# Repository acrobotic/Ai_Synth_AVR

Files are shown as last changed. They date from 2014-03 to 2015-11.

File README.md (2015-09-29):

## Ai\_Synth\_AVR

PCB design files (EAGLE) and example Arduino firmware for a MIDI Synthesizer
based on the ATMega328 MCU.

## Description

For more details, check out the product page at:

   * https://acrobotic.com/kit-00002

Designed by ACROBOTIC Industries.  Please consider buying products from us to 
help fund future Open-Source projects like this! We’ll always put our best 
effort in every project, and release all our design files and code for you to 
use. 

## License

Released under the Creative Commons Attribution, Share-Alike license. Please 
check LICENSE.txt for more information. All text above must be included in any 
redistribution.

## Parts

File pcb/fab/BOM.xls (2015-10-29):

Ai Synth AVR – BOM
Cisco Zabala (x1sc0@acrobotic.com) last updated: 29.10.2015
Manufacturer | Manuf. Part Number | Vendor | Vendor Part Number | Type | Designator | Qty | Description | Case | SMD, BGA, LCC, OR TH | Notes
 |  | Acrobotic | RES-00034-103 | Resistors | R1, R6 | 2 | RES 10K OHM 1/4W 5% CARBON FILM |  | TH
 |  | Acrobotic | RES-00034-271 |  | R2, R3, R5 | 3 | RES 270 OHM 1/4W 5% CARBON FILM |  | TH
 |  | Acrobotic | RES-00034-221 |  | R4 | 1 | RES 220 OHM 1/4W 5% CARBON FILM |  | TH
 |  | Acrobotic | RES-00034-472 |  | R7 | 1 | RES 4.7K OHM 1/4W 5% CARBON FILM |  | TH
 |  | Acrobotic | RES-00010 | Pots | VR1, VR2, VR3, VR4, VR5 | 5 | POT ROTARY 10K OHM 9MM SNAPIN |  | TH
 |  | Acrobotic | RES-00011 |  | VR6 | 1 | TRIMMER 10K OHM 0.2W PC PIN |  | TH | OPTIONAL
 |  | Acrobotic | CAP-00003 | Capacitors | C1, C2 | 2 | CAP ALUM 4.7UF 50V 20% RADIAL |  | TH
 |  | Acrobotic | CAP-00001 | Cap. | C3, C4 | 2 | CAP CER 22PF 50V 5% RADIAL |  | TH
 |  | Acrobotic | CAP-00004 | Cap. | C5, C6 | 2 | CAP CER 0.047UF 50V 10% RADIAL |  | TH
 |  | Acrobotic | CAP-00002 | Cap. | C7 | 1 | CAP CER 0.1UF 50V 10% RADIAL |  | TH
 |  | Acrobotic | IND-00001 | Inductors | L1, L2 | 2 | INDUCTOR FIXED 4700UH 5% RADIAL |  | TH
 |  | Acrobotic | DIO-00001 | Diodes | D1 | 1 | DIODE SMALL SIG 100V 0.2A DO35 |  | TH
 |  | Acrobotic | DIO-00007 |  | D2 | 1 | DIODE GEN PURPOSE 50V 1A DO41 |  | TH
 |  | Acrobotic | FRQ-00001 | Crystal | Q1 | 1 | CRYSTAL 16MHZ 18PF THRU |  | TH
 |  | Acrobotic | CHP-00001 | ICs | (IC1) | 1 | IC MCU 8BIT 32KB FLASH 28DIP |  | TH
 |  | Acrobotic | CHP-00004 | IC | U1 | 1 | IC REG LDO 5V 1.5A TO220 |  | TH
 |  | Acrobotic | CHP-00005 | IC | (U2) | 1 | IC OPAMP GP R-R 730KHZ DUAL 8DIP |  | TH
 |  | Acrobotic | CHP-00006 | IC | (U3) | 1 | OPTOPCOUPLER DARL 5KVRMS 8DIP |  | TH
 |  | Acrobotic | BTN-00002 | Buttons | S1, S2, S3, S4, S5, S6, S7 | 7 | SWITCH TACTILE SPST-NO 0.05A 12V |  | TH
 |  | Acrobotic | BTN-00003 | Switches | S8 | 1 | SWITCH SLIDE SPDT 30V.2A PC MNT |  | TH | ON/OFF
 |  | Acrobotic | CON-00007 | Connectors | J1 | 1 | 2-Pin Screw Terminal Block (3.5mm) |  | TH | PWR
 |  | Acrobotic | CON-00005 | Connect. | J2 | 1 | 0.1" Pitch, 6-Pin (Male, R/A) |  | TH | FTDI
 |  | Acrobotic | CON-00004 | Connect. | J3, J4 | 2 | 0.1" Pitch, 8-Pin (Female) |  | TH | LCD
 |  | Acrobotic | CON-00015 | Connectors | J5 | 1 | CONN DIN 5 PIN FEMALE PCB |  | TH | MIDIJACK
 |  | Acrobotic | CON-00013 | Connect. | 3.5mm | 1 | CONN JACK STEREO R/A 3PIN 3.5MM |  | TH | AUDIOJACK
 |  | Acrobotic | CON-00017 | Socket | U2, U3 | 2 | CONN IC SOCKET VERT 8POS TIN |  | TH | IC SOCKET
 |  | Acrobotic | CON-00016 | Socket | IC1 | 1 | CONN IC SOCKET VERT 28POS TIN |  | TH | IC SOCKET
 |  | Acrobotic | PWR-00007 | Connect. | (J1) | 1 | SNAPS 9V 6" LEADS l-STYLE |  | TH | PWR
 |  | Acrobotic | CON-00010 |  | ISP | 1 | CONN HEADER 6POS .100" VERT 15AU |  | TH | ICSP
 |  | Acrobotic | CON-00002 | Connect. | (J3, J4) | 2 | 0.1” Pitch, 8-Pin (Male) |  | TH | LCD HEADERS
 |  | Acrobotic | LCD-00001 | LCD | (J3, J4) | 1 | Graphic LCD 84x48 - Nokia 5110 |  | TH | LCD MODULE
 |  | Acrobotic | HWR-00002 | Hardware | - | 4 | 4-40 x 7/16" Female / Female Stand-off (3/16" Hex) |  | - | MOUNTS
 |  | Acrobotic | HWR-00024 |  | - | 4 | 4-40 x 3/16" Machine Screws (Phillips Head) |  | - | MOUNTS

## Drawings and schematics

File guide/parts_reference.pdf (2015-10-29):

## ACROBOTIC AVR Synthesizer - Parts List

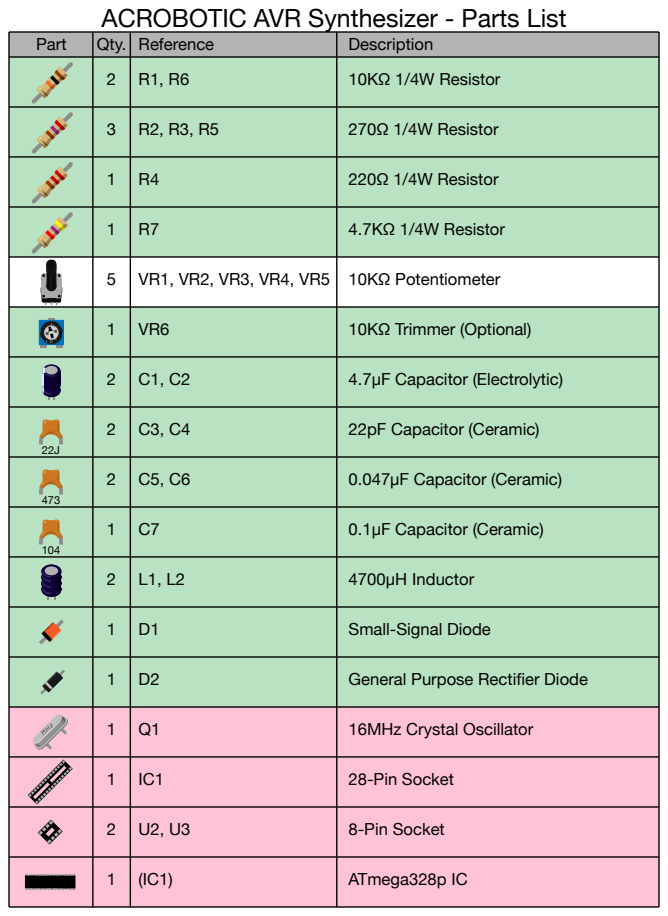
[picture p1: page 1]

Part | Qty. | Reference | Description
2 | R1, R6 | 10KΩ 1/4W Resistor

3 | R2, R3, R5 | 270Ω 1/4W Resistor

1 | R4 | 220Ω 1/4W Resistor

1 | R7 | 4.7KΩ 1/4W Resistor

5 | VR1, VR2, VR3, VR4, VR5 | 10KΩ Potentiometer

1 | VR6 | 10KΩ Trimmer (Optional)

2 | C1, C2 | 4.7μF Capacitor (Electrolytic)

22J | | | 2 | C3, C4 | 22pF Capacitor (Ceramic)

473 | | | 2 | C5, C6 | 0.047μF Capacitor (Ceramic)

104 | | | 1 | C7 | 0.1μF Capacitor (Ceramic)

2 | L1, L2 | 4700μH Inductor

1 | D1 | Small-Signal Diode

1 | D2 | General Purpose Rectifier Diode

1 | Q1 | 16MHz Crystal Oscillator

1 | IC1 | 28-Pin Socket

2 | U2, U3 | 8-Pin Socket

1 | (IC1) | ATmega328p IC

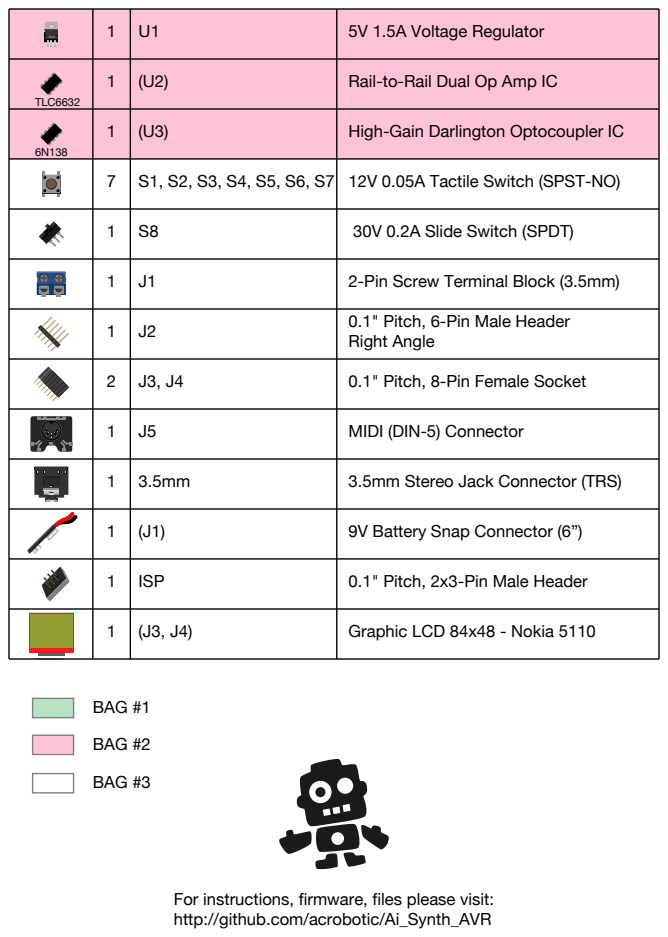
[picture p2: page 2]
BAG #1 BAG #2 BAG #3; 78xxl

1 | U1 | 5V 1.5A Voltage Regulator

TLC6632 | 1 | (U2) | Rail-to-Rail Dual Op Amp IC

6N138 | 1 | (U3) | High-Gain Darlington Optocoupler IC

7 | S1, S2, S3, S4, S5, S6, S7 | 12V 0.05A Tactile Switch (SPST-NO)

1 | S8 | 30V 0.2A Slide Switch (SPDT)

1 | J1 | 2-Pin Screw Terminal Block (3.5mm)
J2 | 0.1" Pitch, 6-Pin Male Header Right Angle 1

2 | J3, J4 | 0.1" Pitch, 8-Pin Female Socket

1 | J5 | MIDI (DIN-5) Connector

1 | 3.5mm | 3.5mm Stereo Jack Connector (TRS)

1 | (J1) | 9V Battery Snap Connector (6”)

1 | ISP | 0.1" Pitch, 2x3-Pin Male Header

1 | (J3, J4) | Graphic LCD 84x48 - Nokia 5110

For instructions, firmware, files please visit:
http://github.com/acrobotic/Ai_Synth_AVR

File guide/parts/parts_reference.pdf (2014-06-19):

## Acrobotic AVR Synthesizer

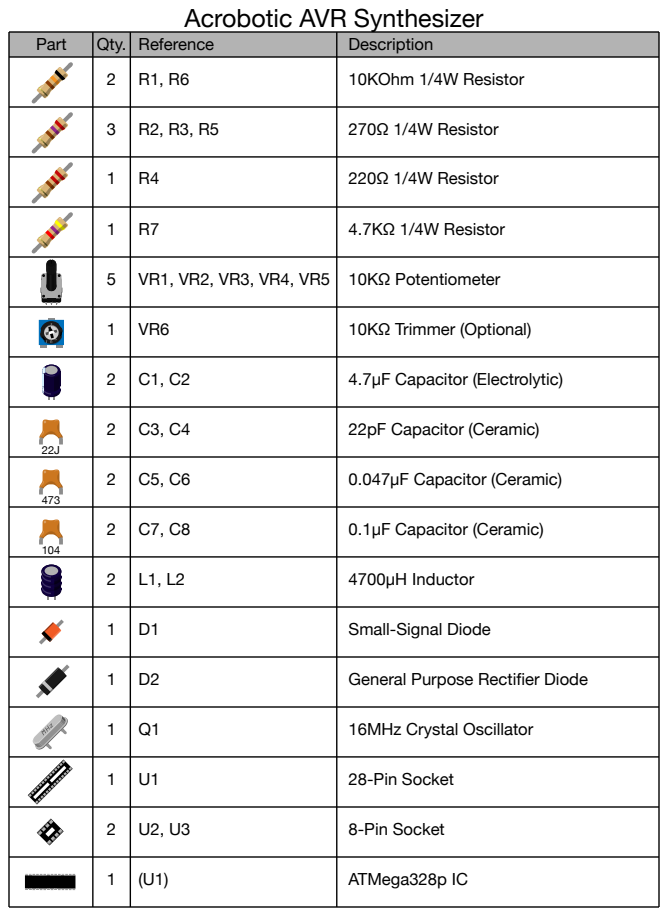
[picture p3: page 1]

Part | Qty. | Reference | Description
2 | R1, R6 | 10KOhm 1/4W Resistor

3 | R2, R3, R5 | 270Ω 1/4W Resistor

1 | R4 | 220Ω 1/4W Resistor

1 | R7 | 4.7KΩ 1/4W Resistor

5 | VR1, VR2, VR3, VR4, VR5 | 10KΩ Potentiometer

1 | VR6 | 10KΩ Trimmer (Optional)

2 | C1, C2 | 4.7μF Capacitor (Electrolytic)

22J | | | 2 | C3, C4 | 22pF Capacitor (Ceramic)

473 | | | 2 | C5, C6 | 0.047μF Capacitor (Ceramic)

104 | | | 2 | C7, C8 | 0.1μF Capacitor (Ceramic)

2 | L1, L2 | 4700μH Inductor

1 | D1 | Small-Signal Diode

1 | D2 | General Purpose Rectifier Diode

1 | Q1 | 16MHz Crystal Oscillator

1 | U1 | 28-Pin Socket

2 | U2, U3 | 8-Pin Socket

1 | (U1) | ATMega328p IC

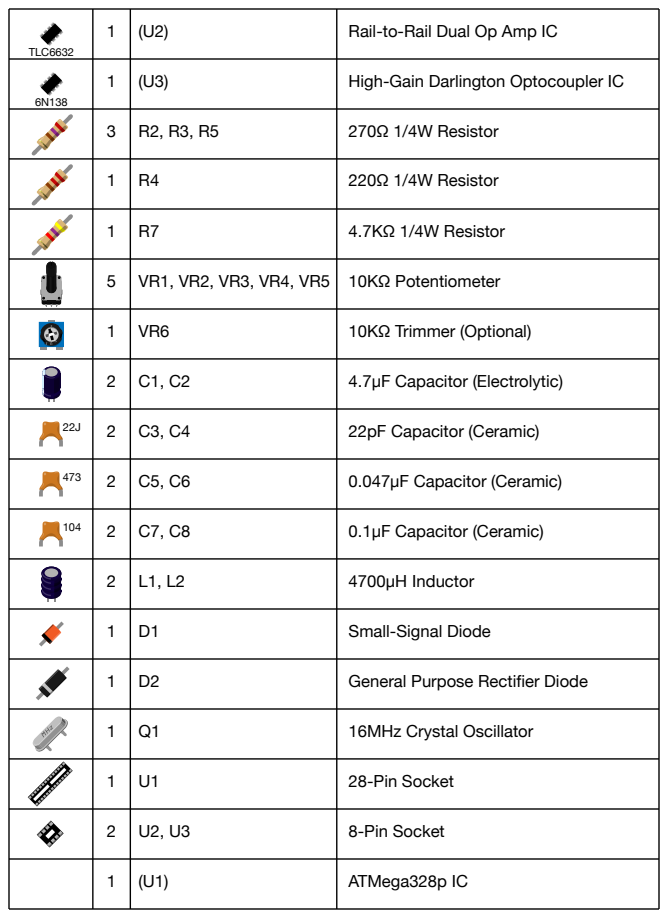
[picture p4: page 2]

TLC6632 | 1 | (U2) | Rail-to-Rail Dual Op Amp IC

6N138 | 1 | (U3) | High-Gain Darlington Optocoupler IC

3 | R2, R3, R5 | 270Ω 1/4W Resistor

1 | R4 | 220Ω 1/4W Resistor

1 | R7 | 4.7KΩ 1/4W Resistor

5 | VR1, VR2, VR3, VR4, VR5 | 10KΩ Potentiometer

1 | VR6 | 10KΩ Trimmer (Optional)

2 | C1, C2 | 4.7μF Capacitor (Electrolytic)

2 | C3, C4 | 22pF Capacitor (Ceramic) ²²J

473 | | | 2 | C5, C6 | 0.047μF Capacitor (Ceramic)

104 | | | 2 | C7, C8 | 0.1μF Capacitor (Ceramic)

2 | L1, L2 | 4700μH Inductor

1 | D1 | Small-Signal Diode

1 | D2 | General Purpose Rectifier Diode

1 | Q1 | 16MHz Crystal Oscillator

1 | U1 | 28-Pin Socket

2 | U2, U3 | 8-Pin Socket

1 | (U1) | ATMega328p IC

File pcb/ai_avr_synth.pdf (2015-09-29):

1

2

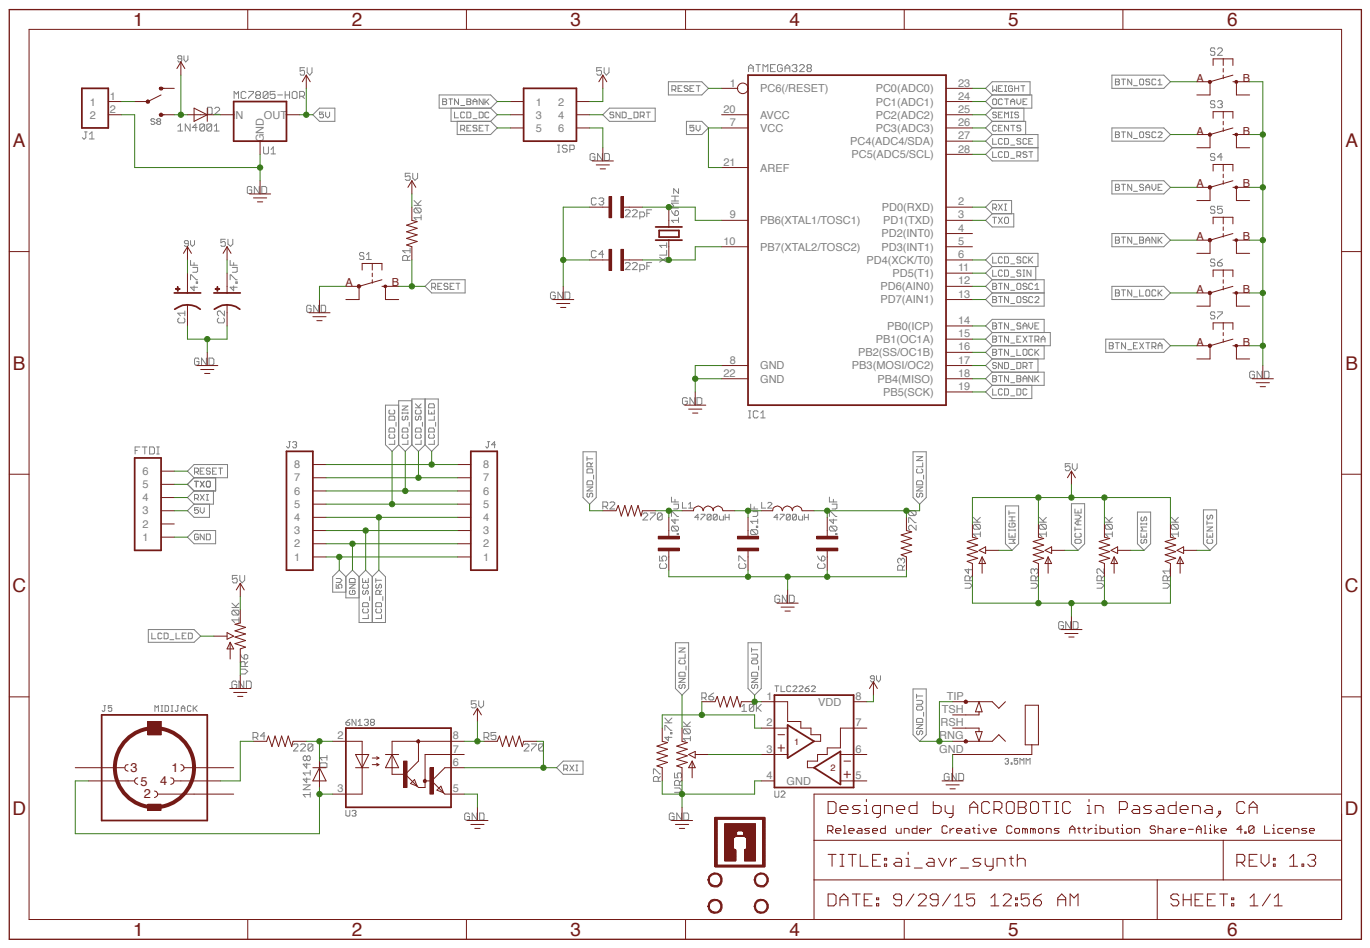
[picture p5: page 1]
GNDOUT; PB5(SCK); PB7(XTAL2/TOSC2) 10; PB6(XTAL1/TOSC1); GND; 8 GND 22; VCC; AREF 21; AVCC 20; PB4(MISO); 18 PB3(MOSI/OC2); 15 PB0(ICP); PD7(AIN1); 13 PD6(AIN0); 11 PD4(XCK/T0); 6 PD3(INT1); 5 PD2(INT0); 4 PD1(TXD); 3 PD0(RXD); PC5(ADC5/SCL); 28 PC4(ADC4/SDA); 27 PC3(ADC3); 26 PC2(ADC2); 25 PC1(ADC1); 24 PC0(ADC0); 23 PC6(/RESET); VDD; TIP TSH RSH RNG GND; ABCD

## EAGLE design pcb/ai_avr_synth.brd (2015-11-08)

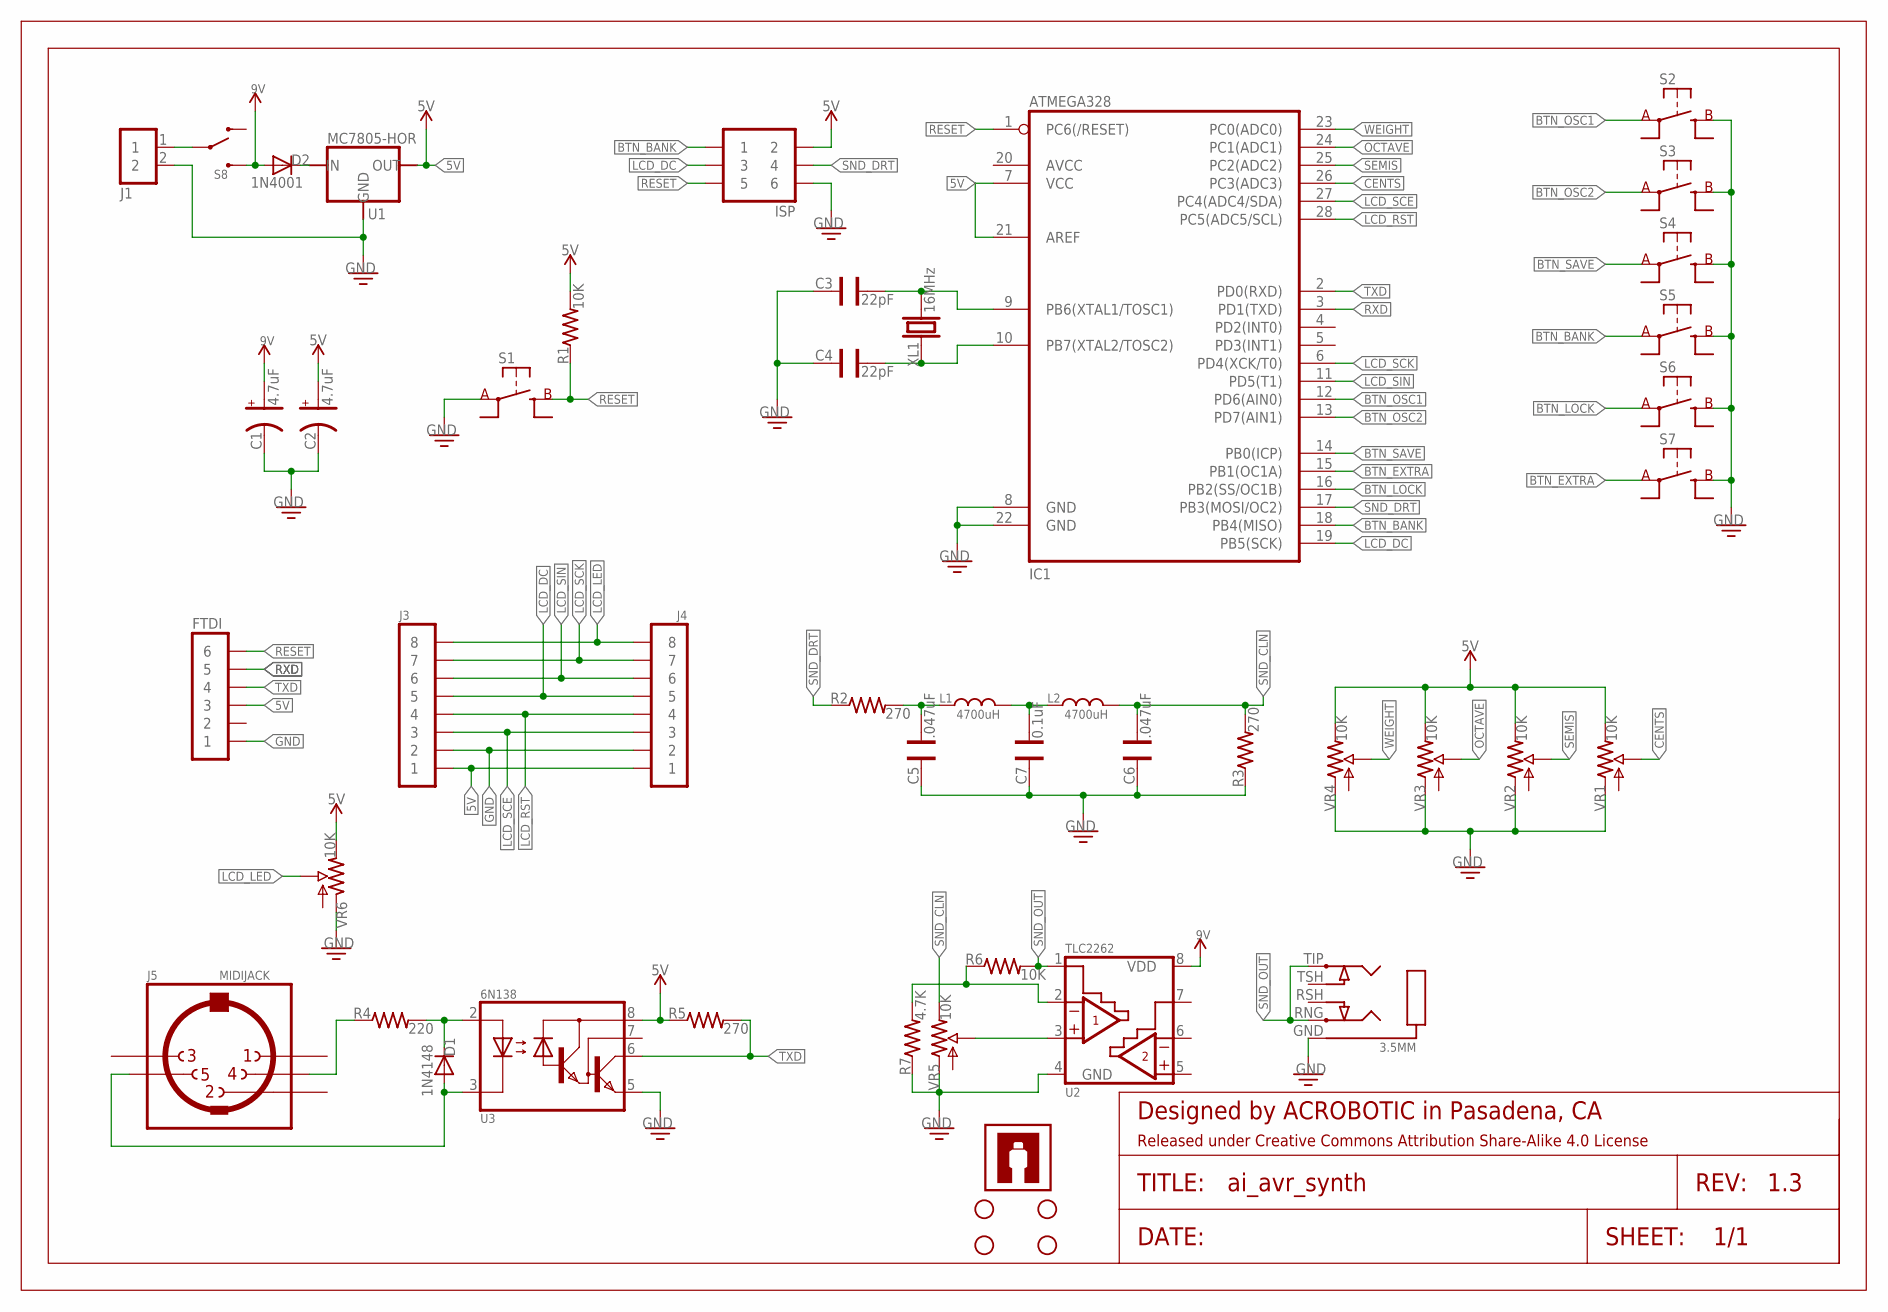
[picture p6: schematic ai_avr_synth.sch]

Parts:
3.5MM: STEREOJACKSJ1-351XNG; SJ1-351XNG
C1, C2: 4.7uF; CAP-POL-025X50
C3, C4: 22pF; CAP-025X050
C5, C6: .047uF; CAP-025X050
C7: 0.1uF; CAP-025X050
D1: 1N4148; TH-1N914
D2: 1N4001; TH-1N914
FRAME1: FRAME-LETTER; CREATIVE-COMMONS
FTDI: 1X06
IC1: ATMEGA328P-PDIP; DIL28
ISP: 2X03
J1: 1X02ST; 1X02-ST
J3, J4: 1X08
J5: MIDIJACK; CP-2350
L1, L2: 4700uH; RLB0912
R1, R6: 10K; RES-AXIAL-0.4
R2, R3, R5: 270; RES-AXIAL-0.4
R4: 220; RES-AXIAL-0.4
R7: 4.7K; RES-AXIAL-0.4
S1, S2, S3, S4, S5, S6, S7: SW-SPSTTH06X06; SW-SPST-TH06X06
S8: SW-SPDTTH; SW-SPDT-TH
STANDOFF5, STANDOFF6, STANDOFF7, STANDOFF8: STAND-OFF4; STAND-OFF-4
U1: MC7805-HOR; TO220
U2: TLC2262; DIL08
U3: 6N138; DIL08
U$5: AI-LOGOXS; AI-LOGO-XS
VR1, VR2, VR3, VR4, VR5: 10K; POT-09X09
VR6: 10K; POT-05X05
XL1: 16MHz; HC49S

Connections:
5V: C2.A, FTDI.3, IC1.7 (VCC), IC1.21 (AREF), ISP.2, J3.1, J4.1, R1.P$2 (2), R5.P$1 (1), U1.OUT, U3.8 (VCC), VR1.P$1 (E), VR2.P$1 (E), VR3.P$1 (E), VR4.P$1 (E), VR6.1 (E)
9V: C1.A, D2.A, S8.3 (L2), U2.8 (VDD)
BTN_BANK: IC1.18 (PB4(MISO)), ISP.1, S5.A@1 (A)
BTN_EXTRA: IC1.15 (PB1(OC1A)), S7.A@1 (A)
BTN_LOCK: IC1.16 (PB2(SS/OC1B)), S6.A@1 (A)
BTN_OSC1: IC1.12 (PD6(AIN0)), S2.A@1 (A)
BTN_OSC2: IC1.13 (PD7(AIN1)), S3.A@1 (A)
BTN_SAVE: IC1.14 (PB0(ICP)), S4.A@1 (A)
CENTS: IC1.26 (PC3(ADC3)), VR1.P$2 (S)
GND: 3.5MM.GND, C1.C, C2.C, C3.2, C4.2, C5.2, C6.2, C7.2, FTDI.1, IC1.8 (GND), IC1.22 (GND), ISP.6, J1.2, J3.2, J4.2, R3.P$1 (1), R7.P$1 (1), S1.A@1 (A), S2.B@1 (B), S3.B@1 (B), S4.B@1 (B), S5.B@1 (B), S6.B@1 (B), S7.B@1 (B), U1.GND, U2.4 (GND), U3.5 (GND), VR1.P$3 (A), VR2.P$3 (A), VR3.P$3 (A), VR4.P$3 (A), VR5.P$3 (A), VR6.3 (A)
LCD_DC: IC1.19 (PB5(SCK)), ISP.3, J3.5, J4.5
LCD_LED: J3.8, J4.8, VR6.2 (S)
LCD_RST: IC1.28 (PC5(ADC5/SCL)), J3.4, J4.4
LCD_SCE: IC1.27 (PC4(ADC4/SDA)), J3.3, J4.3
LCD_SCK: IC1.6 (PD4(XCK/T0)), J3.7, J4.7
LCD_SIN: IC1.11 (PD5(T1)), J3.6, J4.6
unnamed: J5.4, R4.P$1 (1)
unnamed: C4.1, IC1.10 (PB7(XTAL2/TOSC2)), XL1.1
unnamed: C3.1, IC1.9 (PB6(XTAL1/TOSC1)), XL1.2
unnamed: J1.1, S8.2 (COM)
unnamed: D2.C, U1.IN
unnamed: D1.C, R4.P$2 (2), U3.2 (A)
unnamed: D1.A, J5.5, U3.3 (C)
unnamed: U2.3 (1IN+), VR5.P$2 (S)
unnamed: C5.1, L1.2, R2.P$2 (2)
unnamed: C7.1, L1.1, L2.2
unnamed: R6.P$1 (1), R7.P$2 (2), U2.2 (1IN-)
OCTAVE: IC1.24 (PC1(ADC1)), VR3.P$2 (S)
RESET: FTDI.6, IC1.1 (PC6(/RESET)), ISP.5, R1.P$1 (1), S1.B@1 (B)
RXD: FTDI.5, IC1.3 (PD1(TXD))
SEMIS: IC1.25 (PC2(ADC2)), VR2.P$2 (S)
SND_CLN: C6.1, L2.1, R3.P$2 (2), VR5.P$1 (E)
SND_DRT: IC1.17 (PB3(MOSI/OC2)), ISP.4, R2.P$1 (1)
SND_OUT: 3.5MM.RNG, 3.5MM.TIP, R6.P$2 (2), U2.1 (1OUT)
TXD: FTDI.4, IC1.2 (PD0(RXD)), R5.P$2 (2), U3.6 (VO)
WEIGHT: IC1.23 (PC0(ADC0)), VR4.P$2 (S)

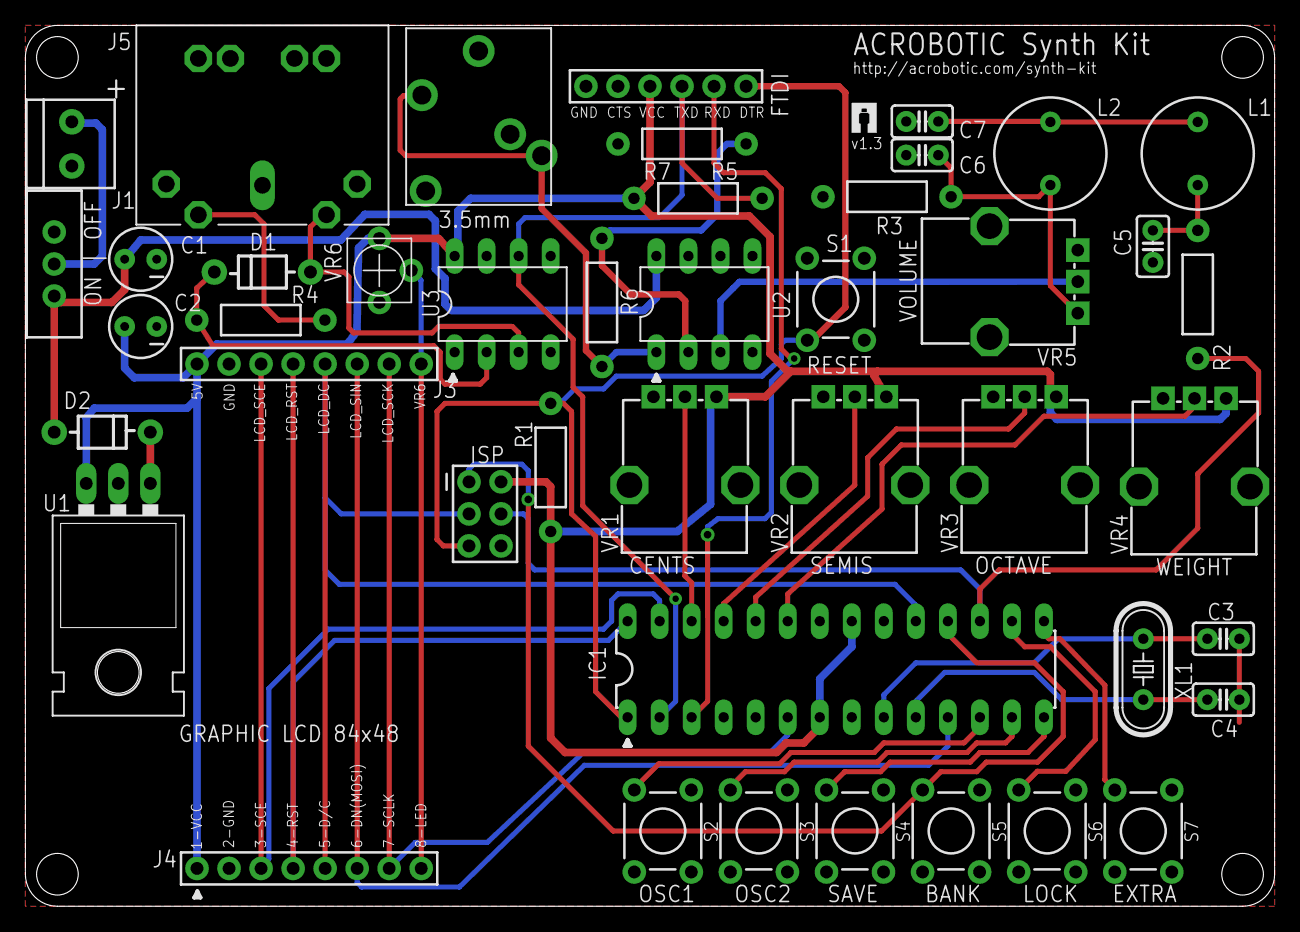
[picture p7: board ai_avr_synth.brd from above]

Board: 2 copper layers, 99.1 x 69.8 mm, 50 parts (0 on the bottom side), 36 nets.

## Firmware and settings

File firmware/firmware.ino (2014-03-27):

/**************************************************************
*
AVR Synthesizer
Author:
Sam Stratter @humanHardDrive

***
Please consider buying products from Acrobotic to help fund future Open-Source projects
like this! We'll always put our best effort in every project, and release all our design
files and code for you to use.
***

Description:
Firmware for the AVR Synthesizer Kit (http://acrobotic.com/catalog/product/view/id/51)
written for the ATMega328p microcontroller using the Arduino IDE v1.0.5.

Using the principle of DDS, the code features:
- 2 Oscillators
- 6 Wave forms (Sine, Triangle, Left Saw, Right Saw, Square, Noise)
- 3 Detune options for second oscillator (Cents, Semitone, Octave)
- Adjustable mixing between two oscillators
- 5 banks

- LFO with 5 wave forms (Sine, Triangle, Left Saw Right Saw, Square)
- LFO routes to control second oscillator detuning (Cents, Semitone, Octave)
- LFO ramps from 0 to 100 hertz

- 20 note arpegiator, relative key control
- Arpegiator ramps from 0 to 50 hertz
- XOR logic modulation
- MIDI in

License:
The contents of this file are licensed under a Creative Commons Attribution-ShareAlike 3.0
Unported License http://creativecommons.org/licenses/by-sa/3.0/.
*
****************************************************************/

#include "avr/pgmspace.h"

#define FASTADC 1

//Wave form defines
#define WAVE_SINE  0
#define WAVE_TRI   1
#define WAVE_LSAW  2
#define WAVE_RSAW  3
#define WAVE_SQU   4
#define WAVE_FLAT  5
#define WAVE_NOISE 6

//LFO route options
#define ROUTE_NONE  0
#define ROUTE_SEMI  1
#define ROUTE_CENT  2
#define ROUTE_OCT   3
#define ROUTE_PHASE	4

//Menu defines
#define MENU_NORM	0
#define MENU_LFO	1
#define MENU_EXTRA	2

//Pin Definitions
#define OSC1_BTN_PIN	6
#define OSC2_BTN_PIN	7
#define LOCK_PIN		10
#define BANK_PIN		12
#define SAVE_PIN		8
#define OSC1_PIN		11
#define EXTRA_PIN		9

#define CENTS_PIN   A3
#define SEMIS_PIN   A2
#define OCTAVE_PIN  A1
#define WEIGHT_PIN  A0

#define LFOFREQ_PIN  A3
#define LFOAMNT_PIN  A2
#define SEQSPD_PIN   A1

//MIDI Commands
#define NOTE_ON		9
#define NOTE_OFF	8
#define AFTERTOUCH	13
#define CC			11
#define PC			12
#define PITCH_WHEEL	14

//MIDI CC
#define CC_osc1WaveForm		0x77
#define CC_osc2WaveForm		0x76
#define CC_cents			0x0E
#define CC_semis			0x0F
#define CC_octave			0x10
#define CC_weight			0x11

#define CC_lfoWaveForm	0x72
#define CC_lfoRoute		0x73
#define CC_lfoSpeed		0x12

#define PIN_SCE   A4 //Pin 3 on LCD
#define PIN_RESET A5 //Pin 4 on LCD
#define PIN_DC    13 //Pin 5 on LCD
#define PIN_SDIN  5 //Pin 6 on LCD
#define PIN_SCLK  4 //Pin 7 on LCD

#define BOUNCE_THRESH 100

//ADC extremes
#define ADC_MIN		5
#define ADC_MAX		1015

//Detune max
#define CENTS_MAX	50
#define OCT_MAX		2
#define SEMIS_MAX	12
#define PHASE_MAX	128

#define WEIGHT_MAX    16
#define NUM_BANKS     5
#define MAX_SEQ_NOTES 20
#define MIDI_OFFSET   20

#define NUM_KEYS	88

//Menu Options
#define OSC1_MAX	WAVE_FLAT
#define OSC2_MAX	WAVE_NOISE
#define LFO_MAX		WAVE_FLAT
#define ROUTE_MAX	ROUTE_PHASE

#define SEQ_PLAYING		0
#define SEQ_STOPPED		1
#define SEQ_SAMPLE		2

//The DC pin tells the LCD if we are sending a command or data
#define LCD_COMMAND 0
#define LCD_DATA  1

//You may find a different size screen, but this one is 84 by 48 pixels
#define LCD_X     84
#define LCD_Y     48

//This table contains the hex values that represent pixels
//for a font that is 5 pixels wide and 8 pixels high
static const byte ASCII[][5] =
{
	{0x00, 0x00, 0x00, 0x00, 0x00} // 20
	,{0x00, 0x00, 0x5f, 0x00, 0x00} // 21 !
	,{0x00, 0x07, 0x00, 0x07, 0x00} // 22 "
	,{0x14, 0x7f, 0x14, 0x7f, 0x14} // 23 #
	,{0x24, 0x2a, 0x7f, 0x2a, 0x12} // 24 $
	,{0x23, 0x13, 0x08, 0x64, 0x62} // 25 %
	,{0x36, 0x49, 0x55, 0x22, 0x50} // 26 &
	,{0x00, 0x05, 0x03, 0x00, 0x00} // 27 '
	,{0x00, 0x1c, 0x22, 0x41, 0x00} // 28 (
	,{0x00, 0x41, 0x22, 0x1c, 0x00} // 29 )
	,{0x14, 0x08, 0x3e, 0x08, 0x14} // 2a *
	,{0x08, 0x08, 0x3e, 0x08, 0x08} // 2b +
	,{0x00, 0x50, 0x30, 0x00, 0x00} // 2c ,
	,{0x08, 0x08, 0x08, 0x08, 0x08} // 2d -
	,{0x00, 0x60, 0x60, 0x00, 0x00} // 2e .
	,{0x20, 0x10, 0x08, 0x04, 0x02} // 2f /
	,{0x3e, 0x51, 0x49, 0x45, 0x3e} // 30 0
	,{0x00, 0x42, 0x7f, 0x40, 0x00} // 31 1
	,{0x42, 0x61, 0x51, 0x49, 0x46} // 32 2
	,{0x21, 0x41, 0x45, 0x4b, 0x31} // 33 3
	,{0x18, 0x14, 0x12, 0x7f, 0x10} // 34 4
	,{0x27, 0x45, 0x45, 0x45, 0x39} // 35 5
	,{0x3c, 0x4a, 0x49, 0x49, 0x30} // 36 6
	,{0x01, 0x71, 0x09, 0x05, 0x03} // 37 7
	,{0x36, 0x49, 0x49, 0x49, 0x36} // 38 8
	,{0x06, 0x49, 0x49, 0x29, 0x1e} // 39 9
	,{0x00, 0x36, 0x36, 0x00, 0x00} // 3a :
	,{0x00, 0x56, 0x36, 0x00, 0x00} // 3b ;
	,{0x08, 0x14, 0x22, 0x41, 0x00} // 3c <
	,{0x14, 0x14, 0x14, 0x14, 0x14} // 3d =
	,{0x00, 0x41, 0x22, 0x14, 0x08} // 3e >
	,{0x02, 0x01, 0x51, 0x09, 0x06} // 3f ?
	,{0x32, 0x49, 0x79, 0x41, 0x3e} // 40 @
	,{0x7e, 0x11, 0x11, 0x11, 0x7e} // 41 A
	,{0x7f, 0x49, 0x49, 0x49, 0x36} // 42 B
	,{0x3e, 0x41, 0x41, 0x41, 0x22} // 43 C
	,{0x7f, 0x41, 0x41, 0x22, 0x1c} // 44 D
	,{0x7f, 0x49, 0x49, 0x49, 0x41} // 45 E
	,{0x7f, 0x09, 0x09, 0x09, 0x01} // 46 F
	,{0x3e, 0x41, 0x49, 0x49, 0x7a} // 47 G
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
};

//Waveform definitions
PROGMEM  prog_uchar waveTable[]  = {
	//sine wave
	0,0,0,0,1,1,1,2,2,3,4,5,5,6,7,9,10,11,12,14,15,16,18,20,21,23,25,27,29,31,33,35,37,39,42,44,46,49,51,54,56,59,62,64,67,
	70,73,76,78,81,84,87,90,93,96,99,102,105,108,111,115,118,121,124,127,130,133,136,139,143,146,149,152,155,158,161,164,167,170,173,176,178,181,184,187,190,192,195,198,200,203,205,208,210,212,215,217,219,
	221,223,225,227,229,231,233,234,236,238,239,240,242,243,244,245,247,248,249,249,250,251,252,252,253,253,253,254,254,254,254,254,254,254,
	253,253,253,252,252,251,250,249,249,248,247,245,244,243,242,240,239,238,236,234,233,231,229,227,225,223,221,219,217,215,212,210,208,205,
	203,200,198,195,192,190,187,184,181,178,176,173,170,167,164,161,158,155,152,149,146,143,139,136,133,130,127,124,121,118,115,111,108,105,
	102,99,96,93,90,87,84,81,78,76,73,70,67,64,62,59,56,54,51,49,46,44,42,39,37,35,33,31,29,27,25,23,21,20,18,16,15,14,12,11,10,9,7,6,5,5,4,
	3,2,2,1,1,1,0,0,0,

	//triangle wave
	1,3,5,7,9,11,13,15,17,19,21,23,25,27,29,31,33,35,37,39,41,43,45,47,49,51,53,55,57,59,61,63,65,67,69,71,73,75,77,79,81,83,85,
	87,89,91,93,95,97,99,101,103,105,107,109,111,113,115,117,119,121,123,125,127,129,131,133,135,137,139,141,143,145,147,149,151,153,155,157,159,161,163,165,167,169,171,173,175,177,179,181,183,185,187,189,191,193,195,
	197,199,201,203,205,207,209,211,213,215,217,219,221,223,225,227,229,231,233,235,237,239,241,243,245,247,249,251,253,255,255,253,251,249,247,
	245,243,241,239,237,235,233,231,229,227,225,223,221,219,217,215,213,211,209,207,205,203,201,199,197,195,193,191,189,187,185,183,181,179,177,
	175,173,171,169,167,165,163,161,159,157,155,153,151,149,147,145,143,141,139,137,135,133,131,129,127,125,123,121,119,117,115,113,111,109,107,
	105,103,101,99,97,95,93,91,89,87,85,83,81,79,77,75,73,71,69,67,65,63,61,59,57,55,53,51,49,47,45,43,41,39,37,35,33,31,29,27,25,23,21,19,17,15,
	13,11,9,7,5,3,1,

	//left saw (negative slope)
	255,254,253,252,251,250,249,248,247,246,245,244,243,242,241,240,239,238,237,236,235,234,233,232,231,230,229,228,227,226,225,224,223,222,221,220,219,218,217,216,215,214,213,
	212,211,210,209,208,207,206,205,204,203,202,201,200,199,198,197,196,195,194,193,192,191,190,189,188,187,186,185,184,183,182,181,180,179,178,177,
	176,175,174,173,172,171,170,169,168,167,166,165,164,163,162,161,160,159,158,157,156,155,154,153,152,151,150,149,148,147,146,145,144,143,142,141,
	140,139,138,137,136,135,134,133,132,131,130,129,128127,126,125,124,123,122,121,120,119,118,117,116,115,114,113,112,111,110,109,108,107,106,105,104,103,102,101,100,99,98,97,96,95,94,93,92,91,90,
	89,88,87,86,85,84,83,82,81,80,79,78,77,76,75,74,73,72,71,70,69,68,67,66,65,64,63,62,61,60,59,58,57,56,55,54,53,52,51,50,49,48,47,46,45,44,43,42,
	41,40,39,38,37,36,35,34,33,32,31,30,29,28,27,26,25,24,23,22,21,20,19,18,17,16,15,14,13,12,11,10,9,8,7,6,5,4,3,2,1,0,

	//right saw (positive slope)
	0,1,2,3,4,5,6,7,8,9,10,11,12,13,14,15,16,17,18,19,20,21,22,23,24,25,26,27,28,29,
	30,31,32,33,34,35,36,37,38,39,40,41,42,43,44,45,46,47,48,49,50,51,52,53,54,55,56,57,58,59,60,61,62,63,64,65,66,67,68,69,70,71,72,73,74,75,76,77,
	78,79,80,81,82,83,84,85,86,87,88,89,90,91,92,93,94,95,96,97,98,99,100,101,102,103,104,105,106,107,108,109,110,111,112,113,114,115,116,117,118,119,
	120,121,122,123,124,125,126,127,128,129,130,131,132,133,134,135,136,137,138,139,140,141,142,143,144,145,146,147,148,149,150,151,152,153,154,155,156,157,158,159,160,161,
	162,163,164,165,166,167,168,169,170,171,172,173,174,175,176,177,178,179,180,181,182,183,184,185,186,187,188,189,190,191,192,193,194,195,196,197,198,199,200,201,202,203,
	204,205,206,207,208,209,210,211,212,213,214,215,216,217,218,219,220,221,222,223,224,225,226,227,228,229,230,231,232,233,234,235,236,237,238,239,
	240,241,242,243,244,245,246,247,248,249,250,251,252,253,254,255,

	//50% duty cycle square wave
	0,0,0,0,0,0,0,0,0,0,0,0,0,0,0,0,0,0,0,0,0,0,0,0,0,0,0,0,0,0,0,0,0,0,0,0,0,0,0,0,0,0,0,0,0,0,0,0,0,0,0,0,0,0,0,0,0,0,0,0,0,0,0,0,
	0,0,0,0,0,0,0,0,0,0,0,0,0,0,0,0,0,0,0,0,0,0,0,0,0,0,0,0,0,0,0,0,0,0,0,0,0,0,0,0,0,0,0,0,0,0,0,0,0,0,0,0,0,0,0,0,0,0,0,0,0,0,0,0,
	255,255,255,255,255,255,255,255,255,255,255,255,255,255,255,255,255,255,255,255,255,255,255,255,255,255,255,255,
	255,255,255,255,255,255,255,255,255,255,255,255,255,255,255,255,255,255,255,255,255,255,255,255,255,255,255,255,255,255,255,
	255,255,255,255,255,255,255,255,255,255,255,255,255,255,255,255,255,255,255,255,255,255,255,255,255,255,255,255,255,255,255,255,
	255,255,255,255,255,255,255,255,255,255,255,255,255,255,255,255,255,255,255,255,255,255,255,255,255,255,255,255,255,255,255,255,255,255,255,255,255,

	//flat wave
	0,0,0,0,0,0,0,0,0,0,0,0,0,0,0,0,0,0,0,0,0,0,0,0,0,0,0,0,0,0,0,0,0,0,0,0,0,0,0,0,0,0,0,0,0,0,0,0,0,0,0,0,0,0,0,0,0,0,0,0,0,0,0,0,
	0,0,0,0,0,0,0,0,0,0,0,0,0,0,0,0,0,0,0,0,0,0,0,0,0,0,0,0,0,0,0,0,0,0,0,0,0,0,0,0,0,0,0,0,0,0,0,0,0,0,0,0,0,0,0,0,0,0,0,0,0,
	0,0,0,0,0,0,0,0,0,0,0,0,0,0,0,0,0,0,0,0,0,0,0,0,0,0,0,0,0,0,0,0,0,0,0,0,0,0,0,0,0,0,0,0,0,0,0,0,0,0,0,0,0,0,0,0,0,0,0,0,0,
	0,0,0,0,0,0,0,0,0,0,0,0,0,0,0,0,0,0,0,0,0,0,0,0,0,0,0,0,0,0,0,0,0,0,0,0,0,0,0,0,0,0,0,0,0,0,0,0,0,0,0,0,0,0,0,0,0,0,0,0,0,0,0,0,0,0,0,0,0,0
};

//Note frequencies
double keyFreq[] = {
	27.5, 29.1352, 30.8677,     //Octave 0
	32.7032, 34.6478, 36.7081, 38.8909, 41.2034, 43.6535, 46.2493, 48.9994, 51.9131, 55, 58.2075, 61.7354,     //Octave 1
	65.4064, 69.2957, 73.4162, 77.7817, 82.4069, 87.3071, 92.4986, 97.9989, 103.826, 110, 116.541, 123.471,    //Octave 2
	130.813, 138.591, 146.832, 155.563, 164.814, 174.614, 184.997, 195.998, 207.652, 220, 233.082, 246.942,    //Octave 3
	261.626, 277.183, 293.665, 311.127, 329.628, 349.228, 369.994, 394.995, 415.305, 440, 466.164, 493.883,    //Octave 4
	523.251, 554.365, 587.330, 622.254, 659.255, 698.456, 739.989, 783.991, 830.609, 880, 932.328, 987.767,    //Octave 5
	1046.50, 1108.73, 1174.66, 1244.51, 1318.51, 1396.91, 1479.98, 1567.98, 1661.22, 1760, 1864.66, 1975.53,   //Octave 6
	2093.00, 2217.46, 2349.32, 2489.02, 2637.02, 2793.83, 2959.96, 3135.96, 3322.44, 3520, 3729.31, 3951.07,   //Octave 7
	4186.01                                                                                                    //Octave 8
};

#define cbi(sfr, bit) (_SFR_BYTE(sfr) &= ~_BV(bit))
#define sbi(sfr, bit) (_SFR_BYTE(sfr) |= _BV(bit))

// const double refclk=31372.549;  // =16MHz / 510
const double refclk=31376.6;      // measured 16MHz

//Phase Accumulators
volatile unsigned long phaccu1 = 0;   // phase accumulator
volatile unsigned long phaccu2 = 0;   // phase accumulator
volatile unsigned long phaccu3 = 0;
volatile unsigned long tword_mOsc1 = 0;  // dds tuning word m
volatile unsigned long tword_mOsc2 = 0;
volatile unsigned long tword_mLFO = 0;

volatile byte osc1;
volatile byte osc2;
volatile byte lfo;

volatile byte smallTimer = 0;
volatile unsigned long millisecs = 0; //because timer0 is disabled

//Detune settings
double centMultiplier = 0; //the number multiplied to the frequency to create cent shift
double cents = 0; //number of cents
int octaveShift = 0;
int semis = 0;
byte phase = 0;

//LFO Settings
volatile int centsRange = 0;
volatile int dCents = 0;
volatile int octaveRange = 0;
volatile int dOctave = 0;
volatile int semisRange = 0;
volatile int dSemis = 0;
volatile int phaseRange = 0;
volatile byte dPhase = 0;

double lfoFreq = 0;
char osc1WaveForm = WAVE_LSAW;
char osc2WaveForm = WAVE_SINE;
char lfoWaveForm = WAVE_FLAT;
char lfoRoute = ROUTE_NONE;
boolean noteSync = false;

//Mixing Settings
boolean xorAddition = false;
volatile byte weight1 = 8;
volatile byte weight2 = 8;

//Button debouncing
boolean osc1BtnPressed = false;
boolean osc2BtnPressed = false;
boolean btnLockPressed = false;
boolean btnSavePressed = false;
boolean btnBankPressed = false;
boolean btnExtraPressed = false;

unsigned long osc1BtnLastPressed = 0;
unsigned long osc2BtnLastPressed = 0;
unsigned long btnLockLastPressed = 0;
unsigned long btnSaveLastPressed = 0;
unsigned long btnBankLastPressed = 0;
unsigned long btnarpLastPressed = 0;
unsigned long btnExtraLastPressed = 0;

//Control Settings
int noteSelect = 44;
boolean notePlaying = false;
byte currentCommand = 0;

//Arpeggio Settings
byte seqMode = SEQ_STOPPED;
int rootKey = 0;
volatile char seq[MAX_SEQ_NOTES];
volatile byte seqMaxNoteCount = 0;
volatile byte seqNoteIndex = 0;
volatile uint16_t arpSpeed = 0;
volatile unsigned long seqTimer = 0;

boolean legato = false; //Not used, yet

//Settings settings
int settingsMenu = 0;
boolean settingsLocked[3];

//Bank Settings
int bankSelect = 1;
int bank[NUM_BANKS][35];

class keyNode
{
	public:
	keyNode()
	{
		keyValue = 0;
		nextNode = NULL;
	}
	
	uint8_t getValue()
	{
		return keyValue;
	}
	
	void setValue(uint8_t value)
	{
		keyValue = value;
	}
	
	void setNextNode(keyNode *node)
	{
		nextNode = node;
	}
	
	keyNode* getNextNode()
	{
		return nextNode;
	}
	
	private:
	uint8_t keyValue;
	keyNode* nextNode;	
};

keyNode* firstNode = NULL;
keyNode* latestNode = NULL;

void setup()
{
	Serial.begin(31250); //The appropriate MIDI communication speed
	//See the SerialEvent() function for more info
	LCDInit();
	clearLCD();
	
	delay(1500);
	
	normalSettingsLCD();

	pinMode(OSC1_PIN, OUTPUT); //PWM pin is an output

	pinMode(OSC1_BTN_PIN, INPUT); //Switch Osc1 waveform button
	digitalWrite(OSC1_BTN_PIN, HIGH); //pull-up, because I can't get used to the "appropriate" way to handle it

	pinMode(OSC2_BTN_PIN, INPUT);  //Switch Osc2 waveform button
	digitalWrite(OSC2_BTN_PIN, HIGH);

	pinMode(LOCK_PIN, INPUT); //Lock preset button
	digitalWrite(LOCK_PIN, HIGH);

	pinMode(BANK_PIN, INPUT); //Bank switch button
	digitalWrite(BANK_PIN, HIGH);

	pinMode(SAVE_PIN, INPUT); //Save preset button
	digitalWrite(SAVE_PIN, HIGH);

	pinMode(EXTRA_PIN, INPUT); //Arpeggio button
	digitalWrite(EXTRA_PIN, HIGH);

	Setup_timer2();

	//disable interrupts to avoid timing distortion
	cbi (TIMSK0,TOIE0);              // disable Timer0 !!! delay() is now not available
	sbi (TIMSK2,TOIE2);              // enable Timer2 Interrupt
	
	#if FASTADC
	// set prescale to 16
	sbi(ADCSRA,ADPS2) ;
	cbi(ADCSRA,ADPS1) ;
	cbi(ADCSRA,ADPS0) ;
	#endif
}

void loop()
{
	osc1BtnCheck();
	osc2BtnCheck();
	
	bankBtnCheck();
	
	saveBtnCheck();
	lockBtnCheck();
	extraBtnCheck();

	if((millisecs - seqTimer > arpSpeed) && notePlaying && seqMaxNoteCount > 0 && seqMode == SEQ_PLAYING) //handle the arpeggio
	{
		noteSelect = rootKey + seq[seqNoteIndex];
		seqTimer = millisecs;

		seqNoteIndex++; //move through the array

		if(seqNoteIndex >= seqMaxNoteCount)
		{
			seqNoteIndex = 0;
		}
		
		if(noteSync)
		{
			phaccu3 = 0;
		}
	}

	if(millisecs % 5 < 5)
	{
		switch(settingsMenu)
		{
			case MENU_NORM:
			if(!settingsLocked[MENU_NORM])
			{
				cents = map(analogRead(CENTS_PIN),ADC_MIN,ADC_MAX,-CENTS_MAX,CENTS_MAX);  //from -100 to 100 cents
				semis = map(analogRead(SEMIS_PIN),ADC_MIN,ADC_MAX,-12,12);  //from -12 to 12 semitone
				octaveShift = map(analogRead(OCTAVE_PIN),ADC_MIN,ADC_MAX,-OCT_MAX, OCT_MAX);  //from -2 to 2 octaves
				weight2 = map(analogRead(WEIGHT_PIN),ADC_MAX,ADC_MIN,WEIGHT_MAX,0);  //weight of osc2 in summation
			}
			break;
			
			case MENU_LFO:
			if(!settingsLocked[MENU_LFO])
			{
				lfoFreq = analogRead(LFOFREQ_PIN)/100.0; //lfo frequency from 0 to 100 hertz
				uint16_t lfoAmnt = analogRead(LFOAMNT_PIN);
				
				centsRange = map(lfoAmnt,ADC_MIN,ADC_MAX,0,CENTS_MAX);
				semisRange = map(lfoAmnt,ADC_MIN,ADC_MAX,0,SEMIS_MAX);
				octaveRange = map(lfoAmnt,ADC_MIN,ADC_MAX,0,3);
				phaseRange = map(lfoAmnt,ADC_MIN,ADC_MAX,0,255);
			}
			break;
			
			case MENU_EXTRA:
			if(!settingsLocked[MENU_EXTRA])
			{
				//phase = map(analogRead(OCTAVE_PIN), ADC_MIN, ADC_MAX, -127, 127);
				arpSpeed = map(analogRead(WEIGHT_PIN),ADC_MIN,ADC_MAX,500,50); //arpSpeed is measured in milliseconds not hertz
			}
			break;
		}
	}

	noteUpdate(); //update the notes every 2 milliseconds
}

void osc1BtnCheck()
{
	if(!digitalRead(OSC1_BTN_PIN))
	{
		if(!osc1BtnPressed && abs(millisecs - osc1BtnLastPressed) > BOUNCE_THRESH)  //debouncing
		{
			osc1BtnPressed = true;
			
			switch(settingsMenu)
			{
				case MENU_NORM:
				if(!settingsLocked[MENU_NORM])
				{
					osc1WaveForm++;
					
					if(osc1WaveForm > OSC1_MAX)
					{
						osc1WaveForm = WAVE_SINE;
					}
					
					phaccu1 = 0;
					osc1Update();
				}
				break;
				
				case MENU_LFO:
				if(!settingsLocked[MENU_LFO])
				{
					lfoWaveForm++;
					
					if(lfoWaveForm > WAVE_FLAT)
					{
						lfoWaveForm = WAVE_SINE;
					}
					
					lfoUpdate();
				}
				break;
				
				case MENU_EXTRA:
				if(!settingsLocked[MENU_EXTRA])
				{
					xorAddition = !xorAddition;
					
					xorUpdate();
				}
				break;
			}
		}
	}
	else
	{
		if(osc1BtnPressed)
		{
			osc1BtnLastPressed = millisecs;
			osc1BtnPressed = false;
		}
	}
}

void osc2BtnCheck()
{
	if(!digitalRead(OSC2_BTN_PIN))
	{
		if(!osc2BtnPressed && abs(millisecs - osc2BtnLastPressed) > BOUNCE_THRESH)
		{
			osc2BtnPressed = true;

			switch(settingsMenu)
			{
				case MENU_NORM:
				if(!settingsLocked[MENU_NORM])
				{
					osc2WaveForm++;
					
					if(osc2WaveForm > WAVE_NOISE)
					{
						osc2WaveForm = WAVE_SINE;
					}
					
					phaccu2 = 0;
					osc2Update();
				}
				break;
				
				case MENU_LFO:
				if(!settingsLocked[MENU_LFO])
				{
					lfoRoute++;
					
					if(lfoRoute > ROUTE_PHASE)
					{
						lfoRoute = ROUTE_NONE;
					}
					
					routeUpdate();
				}
				break;
				
				case MENU_EXTRA:
				if(!settingsLocked[MENU_EXTRA])
				{
					legato = !legato;
					
					legatoUpdate();
				}
				break;
			}
		}
	}
	else
	{
		if(osc2BtnPressed)
		{
			osc2BtnLastPressed = millisecs;
			osc2BtnPressed = false;
		}
	}
}

void lockBtnCheck()
{
	if(!digitalRead(LOCK_PIN))
	{
		if(!btnLockPressed && abs(millisecs - btnLockLastPressed) > BOUNCE_THRESH)
		{
			btnLockPressed = true;

			settingsLocked[settingsMenu] = !settingsLocked[settingsMenu];

			lockUpdate();
		}
	}
	else
	{
		if(btnLockPressed)
		{
			btnLockLastPressed = millisecs;
			btnLockPressed = false;
		}
	}
}

void bankBtnCheck()
{
	if(!digitalRead(BANK_PIN))
	{
		if(!btnBankPressed && abs(millisecs - btnBankLastPressed) > BOUNCE_THRESH)
		{
			btnBankPressed = true;

			switch(settingsMenu)
			{
				case MENU_NORM:
				bankSelect++;
				if(bankSelect > NUM_BANKS)
				{
					bankSelect = 1;
				}

				loadPreset(bankSelect);
				normalSettingsLCD();
				break;
				
				case MENU_EXTRA:
				if(seqMode == SEQ_SAMPLE)
				{
					seqMode = SEQ_PLAYING;
				}
				else if(seqMode == SEQ_PLAYING | seqMode == SEQ_STOPPED)
				{
					seqMode = SEQ_SAMPLE;
					
					seqMaxNoteCount = 0; //reset the number of notes
					seqNoteIndex = 0;
					
					for(int i = 0;i < MAX_SEQ_NOTES; i++)
					{
						seq[i] = 0; //reset each note
					}
				}
				
				seqUpdate();
				break;
			}
		}
	}
	else
	{
		if(btnBankPressed)
		{
			btnBankLastPressed = millisecs;
			btnBankPressed = false;
		}
	}
}

void saveBtnCheck()
{
	if(!digitalRead(SAVE_PIN))
	{
		if(!btnSavePressed && abs(millisecs - btnSaveLastPressed) > BOUNCE_THRESH)
		{
			btnSavePressed = true;

			switch(settingsMenu)
			{
				case MENU_NORM:
				savePreset(bankSelect);
				break;
				
				case MENU_LFO:
				if(!settingsLocked[MENU_LFO])
				{
					noteSync = !noteSync;
					
					noteSyncUpdate();
				}
				break;
				
				case MENU_EXTRA:
				if(!settingsLocked[MENU_EXTRA])
				{
					if(seqMode == SEQ_STOPPED)
					{
						seqMode = SEQ_PLAYING;
					}
					else if(seqMode == SEQ_PLAYING)
					{
						seqMode = SEQ_STOPPED;
					}
					else
					{
						seqMode = SEQ_STOPPED;
					}

					seqUpdate();
				}
				break;
			}
		}
	}
	else
	{
		if(btnSavePressed)
		{
			btnSaveLastPressed = millisecs;
			btnSavePressed = false;
		}
	}
}

void extraBtnCheck()
{
	if(!digitalRead(EXTRA_PIN))
	{
		if(!btnExtraPressed && abs(millisecs - btnExtraLastPressed) > BOUNCE_THRESH)
		{
			btnExtraPressed = true;

			settingsMenu++;
			
			if(settingsMenu > MENU_EXTRA)
			{
				settingsMenu = MENU_NORM;
			}
			
			switch(settingsMenu)
			{
				case MENU_NORM:
				normalSettingsLCD();
				break;
				
				case MENU_LFO:
				lfoSettingsLCD();
				break;
				
				case MENU_EXTRA:
				extraSettingsLCD();
				break;
			}

		}
	}
	else
	{
		if(btnExtraPressed)
		{
			btnExtraLastPressed = millisecs;
			btnExtraPressed = false;
		}
	}
}
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

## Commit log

2013-10-02 Revisions on LCD orientation, and positioning of switches/pots.
    [ai_avr_synth.brd, ai_avr_synth.sch]
2013-10-03 Adding gerbers, firmware. Updated README and index.
    [ai_avr_synth.brd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]
2013-10-04 Finalized BOM.
    [BOM.xls, ai_avr_synth.brd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]
2013-10-04 Final version of BOM.xls
    [BOM.xls]
2013-10-04 Updating libraries
    [BOM.xlsx, ai_avr_synth.brd, ai_avr_synth.sch]
2013-10-04 changes to schematic fonts, and audiojack pad names
    [ai_avr_synth.brd, ai_avr_synth.sch]
2013-10-04 minor change to silkscreen.
    [ai_avr_synth.brd]
2013-10-05 Minor formatting change of BOM.
    [BOM.xls]
2013-10-08 Fixed typo in BOM
    [BOM.xls]
2013-10-16 Updated components to use the latest libraries. Had to redo a few traces (nothing major)
    [ai_avr_synth.brd, ai_avr_synth.sch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]
2013-11-21 New version with modifications discussed with @humanHardDrive
    [ai_avr_synth.brd, ai_avr_synth.sch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]
2013-11-25 BOM updated.
    [BOM.xls, ai_avr_synth.sch]
2014-02-06 updated a few components
    [ai_avr_synth.brd, ai_avr_synth.sch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]
2014-02-26 Update firmware.ino
    Updates in optimization and error fixes
    [firmware.ino]
2014-02-28 Update firmware.ino
    Final version. Bank switching working. Very well optimized.
2014-03-27 fixed trimmer footprint
    [ai_avr_synth.brd, ai_avr_synth.sch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]
2014-04-30 Updated BOM
    [BOM.xls]
2014-06-19 working on guide
    [BOM.xls]
2014-07-29 updating guide
    [BOM.xls]
2015-09-29 adding additional licensing information
    [ai_avr_synth.brd, ai_avr_synth.sch]
2015-09-29 adding schematic pdf
2015-10-27 updating guides
    [BOM.xls]
2015-10-29 updating guide and BOM to remove C8
    [BOM.xls]

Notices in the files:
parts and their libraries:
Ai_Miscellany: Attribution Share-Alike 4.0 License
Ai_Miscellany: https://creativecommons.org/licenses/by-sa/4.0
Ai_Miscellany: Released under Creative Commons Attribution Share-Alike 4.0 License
